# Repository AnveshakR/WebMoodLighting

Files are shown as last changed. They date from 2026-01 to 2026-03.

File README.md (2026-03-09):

# LED_WEB

A smart LED lighting control system that integrates WS2812B RGB LED strips with Home Assistant for flexible, remote-free control.

## Overview

This project controls a WS2812B RGB LED strip connected to an ESP32 by interfacing with a **Home Assistant** server on the local network. A custom HA integration creates per-ESP entities and a Lovelace dashboard widget for each strip, with no intermediary server required.

### Key Features

- **No Remote Required**: Control lights directly through Home Assistant
- **Easy Scaling**: Adding a new ESP requires only flashing the firmware with a new name and adding one integration entry in HA — no other changes needed
- **Dashboard Widget**: Each ESP gets a native HA color picker and display mode dropdown
- **Real-Time Audio Visualization**: Strip brightness can follow live audio FFT data posted to the ESP's local endpoint

### Available Lighting Modes

- Solid color display
- Breathing color display
- Audio-visualizer color display (requires external audio source posting to `/update_fft`)
- Color spectrum

## Configuration

Create this `env.h` file in the project directory and fill in the values as per your setup.

```cpp
#ifndef ENV_H
#define ENV_H

// WiFi
const char* WIFI_SSID     = "your_wifi_ssid";
const char* WIFI_PASSWORD = "your_wifi_password";

// Home Assistant
const char* HA_HOST  = "http://YOUR_HA_IP:8123";
const char* HA_TOKEN = "your_long_lived_access_token"; // Profile → Long-Lived Access Tokens

// Identity — IMPORTANT: must match the name entered in the LED ESP HA integration
const char* ESP_NAME = "your_esp_name";

// Strip
#define LED_PIN  5      // GPIO pin connected to the LED strip data line
#define NUM_LEDS 300    // total number of LEDs in your strip

#endif
```

## Installation

### 1. Home Assistant Integration

Clone the repo and copy the integration folder into your HA config directory from within the HA Terminal addon:

```bash
git clone https://github.com/AnveshakR/WebMoodLighting.git /tmp/led_web
cp -r /tmp/led_web/custom_components/led_esp /config/custom_components/
rm -rf /tmp/led_web
```

After copying, restart HA:

```bash
ha core restart
```

### 2. Add an ESP in Home Assistant

After restart, go to **Settings → Devices & Services → Add Integration** and search for **LED ESP**. Enter a name for the ESP (e.g. `desk`). This creates three entities:

| Entity | ID | Purpose |
|---|-----|---|
| Light | `light.<name>` | RGB color and on/off |
| Select | `select.<name>_display_state` | Display mode dropdown |
| Sensor | `sensor.<name>_ip` | ESP IP address (updated on boot) |

### 3. Flash the ESP32

Make sure `env.h` is configured with the **same name** used in step 2, then flash `led_web.ino` via the Arduino IDE. The ESP should be flashed and started after the integration entry exists in HA, since it posts its IP to HA on boot.

### 4. Lovelace Dashboard

Add a **Light card** pointing at `light.<name>` for the color picker, and an **Entities card** or **Tile card** with `select.<name>_display_state` below it. Suggested YAML for a single ESP named `test_lights`:

```yaml
- type: entities
  title: Test Lights LED Strip
  entities:
    - entity: light.test_lights
      name: Color & Power
    - entity: select.test_lights_display_state
      name: Display Mode
    - entity: sensor.test_lights_ip
      name: IP
      icon: mdi:ip-network
```

## 3D Printed Enclosure

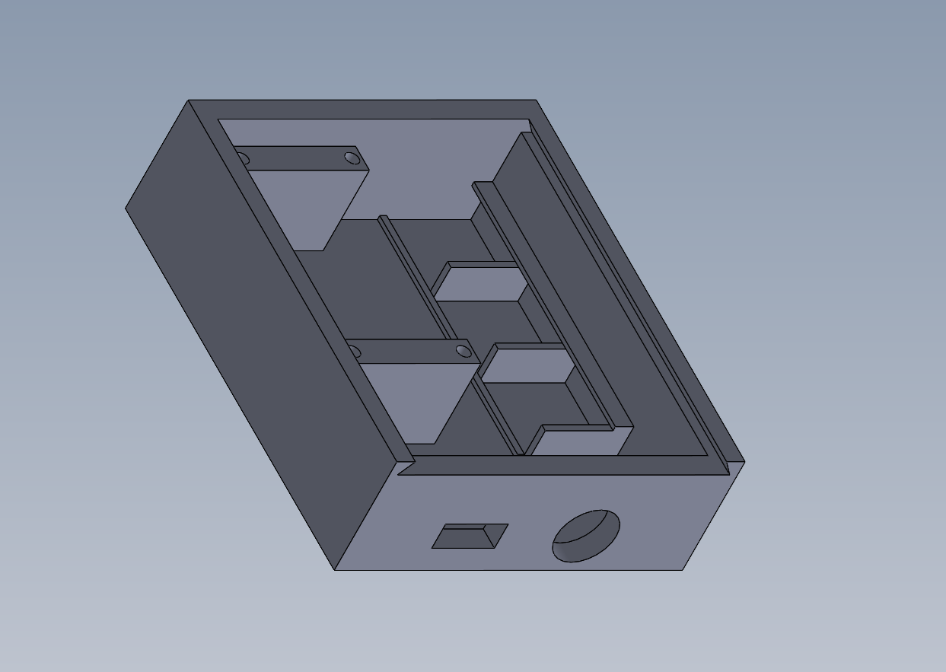
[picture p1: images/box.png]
3D Printed Box


The [3D print files](3D%20print%20files/) folder contains STL files for a custom enclosure to house the ESP32 and wire connections. View them interactively on GitHub: [Box](3D%20print%20files/esp%20box.STL) · [Lid](3D%20print%20files/esp%20box%20lid.STL)

### Required Components

1. **USB-C Connector**: [USB-C Panel Mount Cable](https://a.co/d/ibNtGKY)
2. **WAGO Lever Nut Connectors**: [3-conductor lever nuts × 3](https://a.co/d/3chznWW)
3. **ESP32 Board**: [ESP32 DOIT DevKit V1](https://a.co/d/75TbzBZ)
4. **LED Strip**: [WS2812B LED Strip](https://a.co/d/dlXuyIC)
5. **M3×8 Screws**: 4× screws to secure the ESP32 to the box

### Wiring Connections

Use the three WAGO lever nut connectors to make the following connections:

**Connector 1 (Power +):**
- VIN pin of ESP32
- Positive (+) wire of USB-C connector
- Positive (+) wire of LED strip

**Connector 2 (Ground -):**
- GND pin of ESP32
- Negative (-) wire of USB-C connector
- Negative (-) wire of LED strip

**Connector 3 (Data Signal):**
- Data/TRIG pin of LED strip
- GPIO pin of ESP32 (as defined by `LED_PIN` in env.h, recommended: GPIO 5)

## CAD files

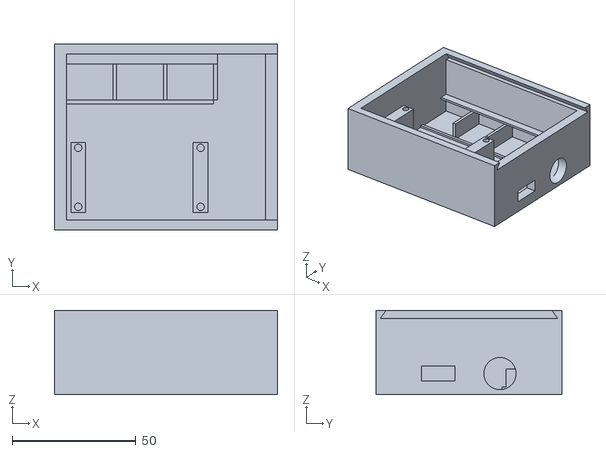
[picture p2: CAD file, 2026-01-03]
3D print files/esp box.STL
90.0 x 75.0 x 34.0

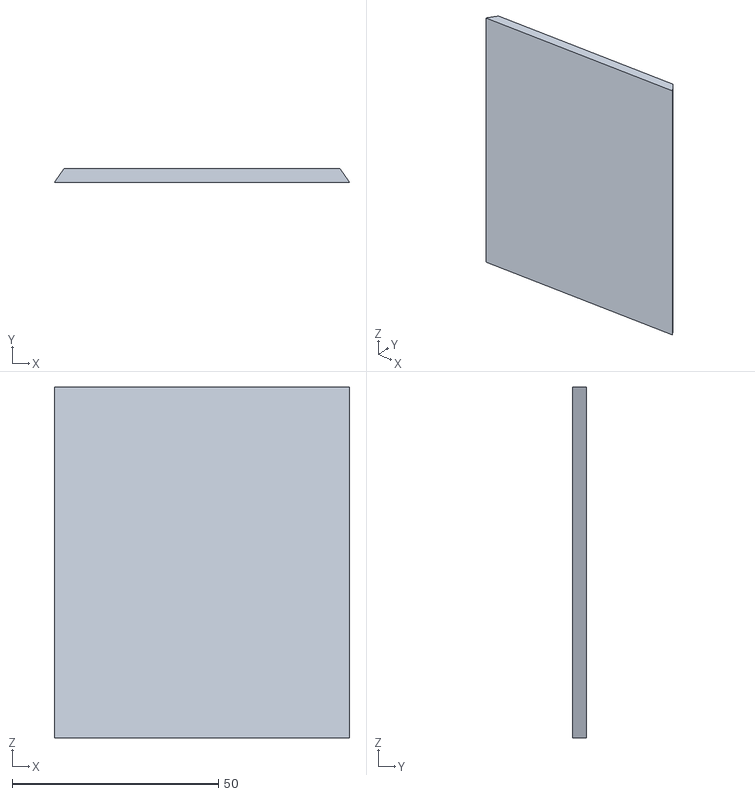
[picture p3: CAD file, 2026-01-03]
3D print files/esp box lid.STL
71.5 x 3.28 x 85.0

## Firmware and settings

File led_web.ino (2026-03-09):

#include <WiFi.h>
#include <HTTPClient.h>
#include <ArduinoJson.h>
#include <NeoPixelBus.h>
#include <WebServer.h>
#include "env.h"
#include "ledfunc.h"

// Server
WebServer server(80);

// Strip
NeoPixelBus<NeoGrbFeature, NeoWs2812xMethod> strip(NUM_LEDS, LED_PIN);
int rgb[3];

// State
float bandLevels[10] = {0};
String current_display_type = "";

// Entities — derived from ESP_NAME in setup()
String ha_light_entity;
String ha_display_entity;
String ha_ip_webhook;


/* Posts the ESP's current IP to Home Assistant via webhook. */
void updateIPInHA() {
  if (WiFi.status() != WL_CONNECTED) return;

  HTTPClient http;
  String payload = "{\"ip\": \"" + WiFi.localIP().toString() + "\"}";

  http.begin(ha_ip_webhook);
  http.addHeader("Content-Type", "application/json");

  int code = http.POST(payload);
  if (code != 200 && code != 201) {
    Serial.println("IP webhook failed: " + String(code));
  }
  http.end();
}

/* Fetches a HA entity state and deserializes it into doc. Returns false on any failure. */
bool getStateFromHA(JsonDocument& doc, const String& entity_id) {
  if (WiFi.status() != WL_CONNECTED) return false;

  HTTPClient http;
  http.begin(String(HA_HOST) + "/api/states/" + entity_id);
  http.addHeader("Authorization", "Bearer " + String(HA_TOKEN));

  int code = http.GET();

  if (code == 200) {
    DeserializationError err = deserializeJson(doc, http.getString());
    http.end();
    if (err) {
      Serial.println("JSON parse error: " + String(err.c_str()));
      return false;
    }
    return true;
  }

  Serial.println("HA request failed (" + entity_id + "): " + String(code));
  http.end();
  return false;
}

/* Reads light.<name> from HA. Sets is_on and updates rgb[]. Returns false on failure. */
bool getLightState(bool& is_on) {
  StaticJsonDocument<512> doc;
  if (!getStateFromHA(doc, ha_light_entity)) return false;

  is_on = (String(doc["state"].as<const char*>()) == "on");

  if (is_on) {
    JsonArray rgb_arr = doc["attributes"]["rgb_color"];
    if (rgb_arr && rgb_arr.size() == 3) {
      rgb[0] = rgb_arr[0];
      rgb[1] = rgb_arr[1];
      rgb[2] = rgb_arr[2];
    } else {
      rgb[0] = rgb[1] = rgb[2] = 255; // IMPORTANT: default white if HA has no color set yet
    }
  }

  return true;
}

/* Reads select.<name>_display_state from HA. Returns current_display_type unchanged on failure. */
String getDisplayMode() {
  StaticJsonDocument<256> doc;
  if (!getStateFromHA(doc, ha_display_entity)) return current_display_type;
  return doc["state"].as<String>();
}

/* Returns true if the current HA display mode still matches expected_mode. Used by animations. */
bool shouldContinueMode(String expected_mode) {
  StaticJsonDocument<256> doc;
  if (!getStateFromHA(doc, ha_display_entity)) return false;
  return doc["state"].as<String>() == expected_mode;
}

/* Sets all LEDs to black. */
void clearStrip() {
  for (int i = 0; i < NUM_LEDS; i++) {
    strip.SetPixelColor(i, RgbColor(0, 0, 0));
  }
  strip.Show();
}

/* POST /update_fft — receives 10 FFT band level floats and updates bandLevels[]. */
void handleUpdateFFT() {
  if (!server.hasArg("plain")) {
    server.send(400, "text/plain", "Missing body");
    return;
  }

  StaticJsonDocument<512> doc;
  DeserializationError error = deserializeJson(doc, server.arg("plain"));
  if (error) {
    server.send(400, "text/plain", "Invalid JSON");
    return;
  }

  JsonArray arr = doc["band_levels"];
  if (!arr || arr.size() != 10) {
    server.send(400, "text/plain", "Expected 10 values");
    return;
  }

  for (int i = 0; i < 10; i++) {
    bandLevels[i] = arr[i].as<float>();
  }

  server.send(200, "application/json", "{\"status\":\"ok\"}");
}

/* GET /status — returns basic ESP health info as JSON. */
void handleStatus() {
  StaticJsonDocument<200> doc;
  doc["status"]    = "ok";
  doc["ip"]        = WiFi.localIP().toString();
  doc["heap"]      = ESP.getFreeHeap();
  doc["uptime"]    = millis() / 1000;
  doc["wifi_rssi"] = WiFi.RSSI();

  String response;
  serializeJson(doc, response);
  server.send(200, "application/json", response);
}


void setup() {
  Serial.begin(115200);

  ha_light_entity   = String("light.")   + ESP_NAME;
  ha_display_entity = String("select.")  + ESP_NAME + "_display_state";
  ha_ip_webhook     = String(HA_HOST)    + "/api/webhook/led_esp_" + ESP_NAME + "_ip";

  strip.Begin();
  strip.Show();

  WiFi.begin(WIFI_SSID, WIFI_PASSWORD);
  int wifi_attempts = 0;
  while (WiFi.status() != WL_CONNECTED && wifi_attempts < 30) {
    delay(1000);
    wifi_attempts++;
  }

  if (WiFi.status() != WL_CONNECTED) {
    Serial.println("WiFi connection failed");
    return;
  }
  Serial.println("WiFi connected: " + WiFi.localIP().toString());

  server.on("/status",     handleStatus);
  server.on("/update_fft", HTTP_POST, handleUpdateFFT);
  server.begin();

  updateIPInHA();
}

void loop() {
  server.handleClient();

  bool light_on;
  if (!getLightState(light_on)) {
    delay(1000);
    return;
  }

  if (!light_on) {
    clearStrip();
    delay(100);
    return;
  }

  current_display_type = getDisplayMode();

  if      (current_display_type == "solid")     solid_mode();
  else if (current_display_type == "breathing") breathing_mode();
  else if (current_display_type == "AV")        AV_mode("2");
  else if (current_display_type == "spectrum")  spectrum_mode(20);

  delay(1);
}

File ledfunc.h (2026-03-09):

#ifndef LEDFUNC_H
#define LEDFUNC_H

#include <NeoPixelBus.h>

// Externs
extern NeoPixelBus<NeoGrbFeature, NeoWs2812xMethod> strip;
extern int rgb[3];
extern float bandLevels[10];

// Prototype
bool shouldContinueMode(String expected_mode);


/* All LEDs set to the current rgb color at 85% brightness. */
void solid_mode() {
  for (int i = 0; i < NUM_LEDS; i++) {
    strip.SetPixelColor(i, RgbColor(rgb[0]*0.85, rgb[1]*0.85, rgb[2]*0.85));
  }
  strip.Show();
  delay(1);
}

/* Pulses the strip through a Gaussian brightness curve. Checks HA for mode changes every frame. */
void breathing_mode() {
  int gauss_size = 100;
  float gauss[100] = { 5, 5, 5, 5, 5, 5, 6, 6, 6, 6, 6, 7, 7, 7, 8, 9, 9, 10, 11, 12, 13, 14, 16, 17, 19, 21, 23, 26, 28, 31, 34, 37, 40, 43, 47, 45, 54, 57, 60, 64, 67, 70, 73, 76,
                     78, 80, 82, 83, 84, 85, 85, 85, 84, 83, 82, 80, 78, 76, 73, 70, 67, 64, 60, 57, 54, 45, 47, 43, 40, 37, 34, 31, 28, 26, 23, 21, 19, 17, 16, 14, 13, 12, 11, 10,
                     9, 9, 8, 7, 7, 7, 6, 6, 6, 6, 6, 5, 5, 5, 5, 5 };

  for (int i = gauss_size - 1; i >= 0; i--) {
    if (!shouldContinueMode("breathing")) return;
    for (int j = 0; j < NUM_LEDS; j++) {
      strip.SetPixelColor(j, RgbColor((rgb[0] * gauss[i]) / 100, (rgb[1] * gauss[i]) / 100, (rgb[2] * gauss[i]) / 100));
    }
    strip.Show();
    delay(32);
  }
}

/* Brightness of the strip follows a single FFT band level. Degrades to dark strip with no audio source.
   TODO: replace hardcoded band index "2" with a configurable HA entity when audio source is added. */
void AV_mode(String fft_band) {
  int band_index = fft_band.toInt();
  if (band_index < 0 || band_index >= 10) return;

  float scaled_val     = constrain(bandLevels[band_index] / 100.0, 0.0, 3.0);
  float gamma_corrected = constrain(pow(scaled_val / 3.0, 0.4), 0.0, 1.0);
  if (gamma_corrected < 0.02) gamma_corrected = 0.0;

  RgbColor color((int)(rgb[0] * gamma_corrected), (int)(rgb[1] * gamma_corrected), (int)(rgb[2] * gamma_corrected));
  for (int i = 0; i < NUM_LEDS; i++) {
    strip.SetPixelColor(i, color);
  }
  strip.Show();
}

/* Animates a rotating rainbow across the strip. Ignores rgb color. Checks HA for mode changes per frame. */
void spectrum_mode(int speed_delay) {
  static unsigned long last_update = 0;
  static uint16_t hue_offset = 0;

  if (millis() - last_update < speed_delay) return;
  last_update = millis();

  if (!shouldContinueMode("spectrum")) return;

  for (int i = 0; i < NUM_LEDS; i++) {
    uint8_t hue = (i * 255 / NUM_LEDS) + (hue_offset >> 8);
    uint8_t r, g, b;

    if (hue < 85) {
      r = hue * 3;         g = 255 - hue * 3; b = 0;
    } else if (hue < 170) {
      hue -= 85;
      r = 255 - hue * 3;  g = 0;             b = hue * 3;
    } else {
      hue -= 170;
      r = 0;               g = hue * 3;       b = 255 - hue * 3;
    }

    strip.SetPixelColor(i, RgbColor(r, g, b));
  }

  strip.Show();
  hue_offset += 256;
}

#endif

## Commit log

2022-01-17 removed first led flickering by using NPB
2022-06-02 added kicad files
    [led_web-B_Cu.gbr, led_web-B_Fab.gbr, led_web-B_Mask.gbr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]
2022-08-16 pcb redesign
    [led_web-B_Cu.gbr, led_web-B_Fab.gbr, led_web-B_Mask.gbr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]
2025-07-16 initial commit?
    [led_web-B_Cu.gbr, led_web-B_Fab.gbr, led_web-B_Mask.gbr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]
2026-01-03 added 3d model files, and some refactoring in the ino files
    [esp box lid.STL, esp box.STL]
2026-01-03 slight tolerance issues in the esp box dimensions, fixed
    [esp box.STL]
2026-03-09 replaced Flask webapp with native HA integration, updated README and cleaned up comments
    [led_web.ino, ledfunc.h]
